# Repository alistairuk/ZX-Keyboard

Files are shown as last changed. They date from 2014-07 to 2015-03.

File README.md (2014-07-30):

ZX-Keyboard
===========

An Arduino based project to convert a broken ZX Spectrum computer in to a USB keyboard.

The full background to this is on by blog at http://www.agm.me.uk/blog/2014/07/zx-keyboard.php
The master source repository is here at https://github.com/alistairuk/ZX-Keyboard
The original build instructions are at http://hackaday.io/project/2076-ZX-Keyboard

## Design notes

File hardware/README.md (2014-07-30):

ZX-Keyboard - Hardware
======================

An Arduino based project to convert a broken ZX Spectrum computer in to a USB keyboard.

This is where we store hardware related documents and diagrams.

The main circuite diagram is produced in fritzing ( http://fritzing.org/download/ ) and exported to PDF.

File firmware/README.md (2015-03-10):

ZX-Keyboard - Hardware
======================

An Arduino based project to convert a broken ZX Spectrum computer in to a USB keyboard.

This is where we store the Arduino sketch for the firmware.

Please note that the VUSB may not compile with the Arduino IDE 1.6 or later. It will compile with 1.0.5.

Please feel free to improve it.

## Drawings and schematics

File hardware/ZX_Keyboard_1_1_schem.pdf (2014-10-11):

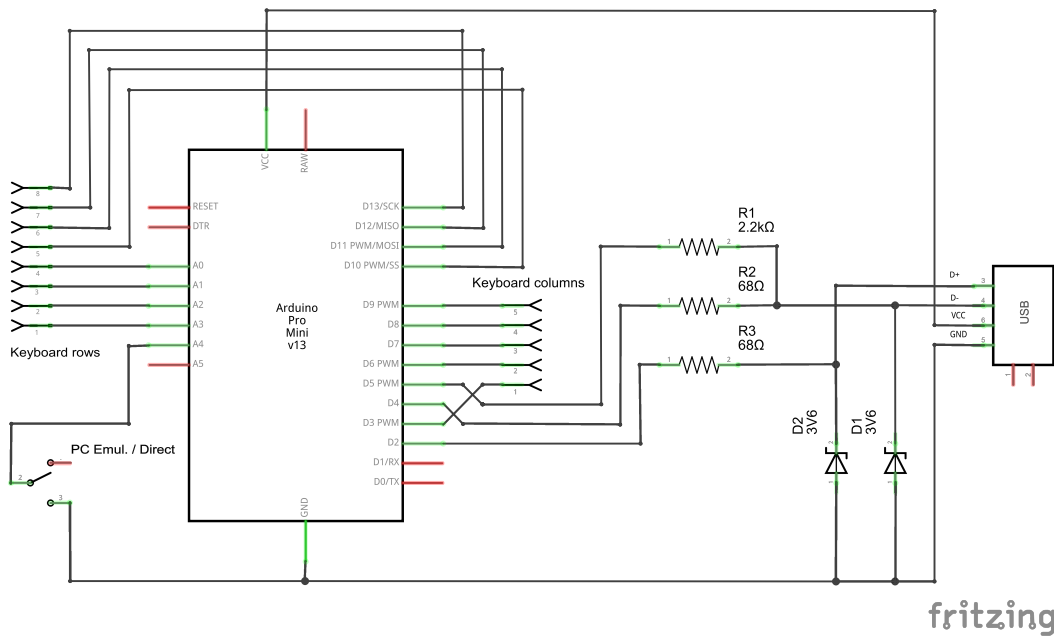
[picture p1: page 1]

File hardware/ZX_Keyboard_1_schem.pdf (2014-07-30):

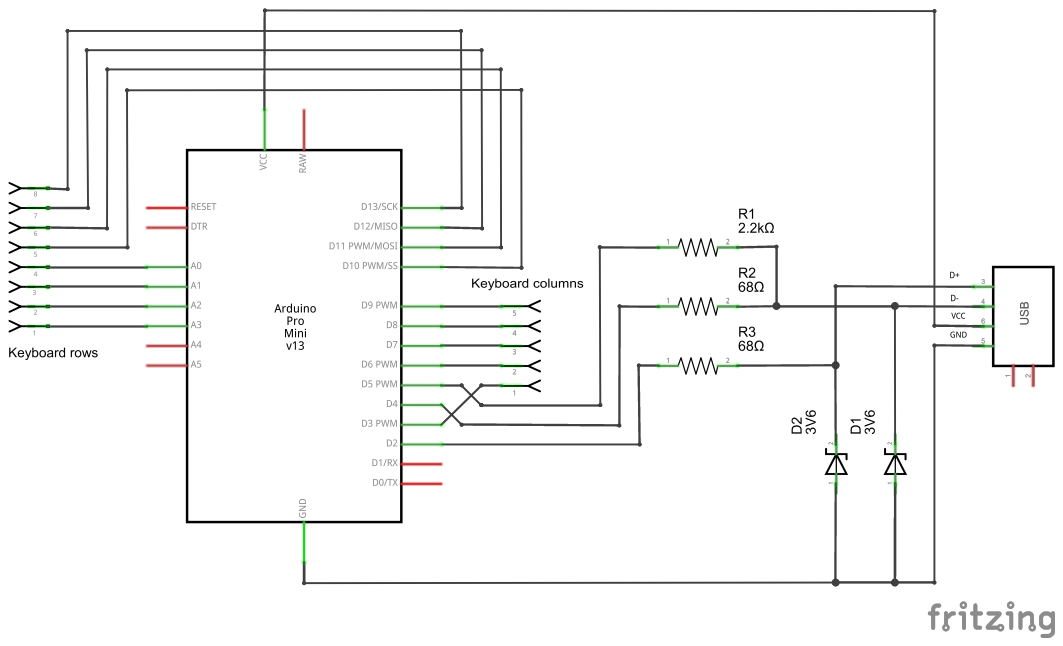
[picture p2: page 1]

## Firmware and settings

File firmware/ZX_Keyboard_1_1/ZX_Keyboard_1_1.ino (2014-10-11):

/*
 * ZX Keyboard
 *
 * Arduino code to use a ZX Spectrum keyboard as a USB keyboard
 *
 * Alistair MacDonald 2014
 *
 */

/*
 * We use the VUSB for Arduino library from http://code.google.com/p/vusb-for-arduino/
 * Download vusb-for-arduino-005 and copy UsbKeyboard from the libraries folder to your libraries folder
 *
 * The Arduino's LED on pin 13 needs to be removed or a pullup resistor to VCC added. This is becuase we use the pin in in INPUT_PULLUP mode.
 *
 * The hardware is as follows....
 *
 * D2 -> 68R Resistor - > USB D+
 * D4 -> 68R Resistor - > USB D-
 * D5 -> 2K2 Resistor - > USB D-
 *
 * USB D+ and D- should be attached to two 3V6 0.5W Zener diodes wiht the anodes connected to ground
 *
 * D3 -> Keyboard Column 1
 * D6 -> Keyboard Column 2
 * D7 -> Keyboard Column 3
 * D8 -> Keyboard Column 4
 * D9 -> Keyboard Column 5
 * PC mapping enable/disable switch -> A4
 * Keyboard Row 1 -> A3
 * Keyboard Row 2 -> A2
 * Keyboard Row 3 -> A1
 * Keyboard Row 4 -> A0
 * Keyboard Row 5 -> D10
 * Keyboard Row 6 -> D11
 * Keyboard Row 7 -> D12
 * Keyboard Row 8 -> D13
 *
 * Full background at http://www.agm.me.uk/blog/2014/07/zx-keyboard.php
 * Master source repository at https://github.com/alistairuk/ZX-Keyboard (please feed back and contribute)
 * Original build instructions at http://hackaday.io/project/2076-ZX-Keyboard
 *
 * Apologies for this not being as readable as I would like. Some parts are a little more complex than  they might at first appear.
 *
 * Changes:
 *
 * 1.0 - Original firmware release
 *
 * 1.1 - Added a switch to A4 to enable / disable PC key mapping
 *
 */
 
#include "UsbKeyboard.h"

// Global varables
byte currentPressed[5]; // Stores the bitmask for currently pressed buttons
byte lastPressed[5];    // Stores the bitmask for the buttons pressed last time
uchar reportBuffer[4];  // Buffer for HID data (1 modifier byte and up to 3 keys)

// Setup everything
void setup() {
  // Set column pins to floating
  pinMode(3, INPUT);
  pinMode(6, INPUT);
  pinMode(7, INPUT);
  pinMode(8, INPUT);
  pinMode(9, INPUT);
  // Set row pins to pullup
  pinMode(10, INPUT_PULLUP);
  pinMode(11, INPUT_PULLUP);
  pinMode(12, INPUT_PULLUP);
  pinMode(13, INPUT_PULLUP);
  pinMode(A0, INPUT_PULLUP);
  pinMode(A1, INPUT_PULLUP);
  pinMode(A2, INPUT_PULLUP);
  pinMode(A3, INPUT_PULLUP);
  pinMode(A4, INPUT_PULLUP);
  // Disable timer0 overflow interrupt
  // This is done to prevent it interupting USB communication
  TIMSK0&=!(1<<TOIE0);
}

// A dleay rputeen with the same functionality as delay() but will work with timer0 disabled
void delay2(unsigned long inDelay) {
  for (int loopIt=0; loopIt<inDelay; loopIt++) {
    delayMicroseconds(1000);
  }
}

// Read the state of one row of keys
byte readRow(int rowPin) {
  // Seet the row pin to low
  pinMode(rowPin, OUTPUT);
  digitalWrite(rowPin, LOW);
  // Read the values from the columns
  // Sorry about it looking complex. It does the same as 8 digitalRead() calls.
  byte result = (~PINB>>2 & B00001111) | (~PINC<<4 & B11110000);
  // Set the row pin back to floating
  pinMode(rowPin, INPUT);
  // All done, return the value  
  return result;
}

// Clear the buffer for HID data
void clearReportBuffer() {
  memset(reportBuffer, 0, sizeof(reportBuffer));
}

// Insert one keycode to the buffer for HID data
void addReportBufferValue(int inKeystroke) {
  memcpy(reportBuffer+2, reportBuffer+1, sizeof(reportBuffer)-2);
  reportBuffer[1] = inKeystroke;
}

// Populate the HID buffer based on the currently pressed buttons in currentPressed[] (PC mapping)
void fillReportBuffer() {
  // Check what keys are being pressed to work out shift state
  int isShiftPressed = currentPressed[0]&0x04;
  int isNumberPressed = ((currentPressed[0]&0x90) || (currentPressed[1]&0x90) || (currentPressed[2]&0x90) || (currentPressed[3]&0x90) || (currentPressed[4]&0x90));
  int isLetterPressed = ((currentPressed[0]&0x6B) || (currentPressed[1]&0x6F) || (currentPressed[2]&0x6F) || (currentPressed[3]&0x6F) || (currentPressed[4]&0x6F)); // Ignore shift here
  // Set the shift modifier is shift is pressed, but only if no numbers (used for navigation) are pressed or a letter (and other non-number keys) is pressed
  // As odd as it is this will work fully under normal circumstances but will also increase compatibility when used with ZX Spectrum emulators
  int isShifted = isShiftPressed && (!isNumberPressed || isLetterPressed);
  reportBuffer[0] = isShifted ? 0x02 : 0x00;
  // Add keycodes for any keys pressed to the HID buffer
  // Row 0
  // Note: We only chage the modifyer when Caps Shift is pressed
  if (currentPressed[0]&0x01) addReportBufferValue(KEY_SPACE);
  if (currentPressed[0]&0x02) addReportBufferValue(KEY_ENTER);
  if (currentPressed[0]&0x08) addReportBufferValue(KEY_P);
  if (!isShiftPressed && (currentPressed[0]&0x10)) addReportBufferValue(KEY_0);
  if (isShiftPressed && (currentPressed[0]&0x10)) addReportBufferValue(0x022A); // Backspace
  if (currentPressed[0]&0x20) addReportBufferValue(KEY_A);
  if (currentPressed[0]&0x40) addReportBufferValue(KEY_Q);
  if (currentPressed[0]&0x80) addReportBufferValue(KEY_1);
  // Row 1
  // Note: This is not called when Symbol Shift is pressed
  if (currentPressed[1]&0x02) addReportBufferValue(KEY_L);
  if (currentPressed[1]&0x08) addReportBufferValue(KEY_O);
  if (currentPressed[1]&0x10) addReportBufferValue(KEY_9);
  if (currentPressed[1]&0x04) addReportBufferValue(KEY_Z);
  if (currentPressed[1]&0x20) addReportBufferValue(KEY_S);
  if (currentPressed[1]&0x40) addReportBufferValue(KEY_W);
  if (!isShiftPressed && (currentPressed[1]&0x80)) addReportBufferValue(KEY_2);
  if (isShiftPressed && (currentPressed[1]&0x80)) addReportBufferValue(0x0039); // Caps Lock
  // Row 2
  if (currentPressed[2]&0x01) addReportBufferValue(KEY_M);
  if (currentPressed[2]&0x02) addReportBufferValue(KEY_K);
  if (currentPressed[2]&0x08) addReportBufferValue(KEY_I);
  if (!isShiftPressed && (currentPressed[2]&0x10)) addReportBufferValue(KEY_8);
  if (isShiftPressed && (currentPressed[2]&0x10)) addReportBufferValue(0x004F); // Right Arrow
  if (currentPressed[2]&0x04) addReportBufferValue(KEY_X);
  if (currentPressed[2]&0x20) addReportBufferValue(KEY_D);
  if (currentPressed[2]&0x40) addReportBufferValue(KEY_E);
  if (currentPressed[2]&0x80) addReportBufferValue(KEY_3);
  // Row 3
  if (currentPressed[3]&0x01) addReportBufferValue(KEY_N);
  if (currentPressed[3]&0x02) addReportBufferValue(KEY_J);
  if (currentPressed[3]&0x08) addReportBufferValue(KEY_U);
  if (!isShiftPressed && (currentPressed[3]&0x10)) addReportBufferValue(KEY_7);
  if (isShiftPressed && (currentPressed[3]&0x10)) addReportBufferValue(0x0052); // Down Arrow
  if (currentPressed[3]&0x04) addReportBufferValue(KEY_C);
  if (currentPressed[3]&0x20) addReportBufferValue(KEY_F);
  if (currentPressed[3]&0x40) addReportBufferValue(KEY_R);
  if (currentPressed[3]&0x80) addReportBufferValue(KEY_4);
  // Row 4
  if (currentPressed[4]&0x01) addReportBufferValue(KEY_B);
  if (currentPressed[4]&0x02) addReportBufferValue(KEY_H);
  if (currentPressed[4]&0x08) addReportBufferValue(KEY_Y);
  if (!isShiftPressed && (currentPressed[4]&0x10)) addReportBufferValue(KEY_6);
  if (isShiftPressed && (currentPressed[4]&0x10)) addReportBufferValue(0x0051); // Down Arrow
  if (currentPressed[4]&0x04) addReportBufferValue(KEY_V);
  if (currentPressed[4]&0x20) addReportBufferValue(KEY_G);
  if (currentPressed[4]&0x40) addReportBufferValue(KEY_T);
  if (!isShiftPressed && (currentPressed[4]&0x80)) addReportBufferValue(KEY_5);
  if (isShiftPressed && (currentPressed[4]&0x80)) addReportBufferValue(0x0050); // Left Arrow
}

// Populate the HID buffer based on the currently pressed buttons in currentPressed[] (direct mapping)
void fillReportBufferDirect() {
  // Check what keys are being pressed to work out shift state
  int isCapsPressed = currentPressed[0]&0x04;
  int isSymbolPressed = currentPressed[1]&0x01;
  // Set the shift modifier is shift is pressed, but only if no numbers (used for navigation) are pressed or a letter (and other non-number keys) is pressed
  // As odd as it is this will work fully under normal circumstances but will also increase compatibility when used with ZX Spectrum emulators
  reportBuffer[0] = (isCapsPressed ? 0x02 : 0x00) + (isSymbolPressed ? 0x01 : 0x00);
  // Add keycodes for any keys pressed to the HID buffer
  // Row 0
  // Note: We only chage the modifyer when Caps Shift is pressed
  if (currentPressed[0]&0x01) addReportBufferValue(KEY_SPACE);
  if (currentPressed[0]&0x02) addReportBufferValue(KEY_ENTER);
  if (currentPressed[0]&0x08) addReportBufferValue(KEY_P);
  if (currentPressed[0]&0x10) addReportBufferValue(KEY_0);
  if (currentPressed[0]&0x20) addReportBufferValue(KEY_A);
  if (currentPressed[0]&0x40) addReportBufferValue(KEY_Q);
  if (currentPressed[0]&0x80) addReportBufferValue(KEY_1);
  // Row 1
  // Note: We only chage the modifyer when Symbol Shift is pressed
  if (currentPressed[1]&0x02) addReportBufferValue(KEY_L);
  if (currentPressed[1]&0x08) addReportBufferValue(KEY_O);
  if (currentPressed[1]&0x10) addReportBufferValue(KEY_9);
  if (currentPressed[1]&0x04) addReportBufferValue(KEY_Z);
  if (currentPressed[1]&0x20) addReportBufferValue(KEY_S);
  if (currentPressed[1]&0x40) addReportBufferValue(KEY_W);
  if (currentPressed[1]&0x80) addReportBufferValue(KEY_2);
  // Row 2
  if (currentPressed[2]&0x01) addReportBufferValue(KEY_M);
  if (currentPressed[2]&0x02) addReportBufferValue(KEY_K);
  if (currentPressed[2]&0x08) addReportBufferValue(KEY_I);
  if (currentPressed[2]&0x10) addReportBufferValue(KEY_8);
  if (currentPressed[2]&0x04) addReportBufferValue(KEY_X);
  if (currentPressed[2]&0x20) addReportBufferValue(KEY_D);
  if (currentPressed[2]&0x40) addReportBufferValue(KEY_E);
  if (currentPressed[2]&0x80) addReportBufferValue(KEY_3);
  // Row 3
  if (currentPressed[3]&0x01) addReportBufferValue(KEY_N);
  if (currentPressed[3]&0x02) addReportBufferValue(KEY_J);
  if (currentPressed[3]&0x08) addReportBufferValue(KEY_U);
  if (currentPressed[3]&0x10) addReportBufferValue(KEY_7);
  if (currentPressed[3]&0x04) addReportBufferValue(KEY_C);
  if (currentPressed[3]&0x20) addReportBufferValue(KEY_F);
  if (currentPressed[3]&0x40) addReportBufferValue(KEY_R);
  if (currentPressed[3]&0x80) addReportBufferValue(KEY_4);
  // Row 4
  if (currentPressed[4]&0x01) addReportBufferValue(KEY_B);
  if (currentPressed[4]&0x02) addReportBufferValue(KEY_H);
  if (currentPressed[4]&0x08) addReportBufferValue(KEY_Y);
  if (currentPressed[4]&0x10) addReportBufferValue(KEY_6);
  if (currentPressed[4]&0x04) addReportBufferValue(KEY_V);
  if (currentPressed[4]&0x20) addReportBufferValue(KEY_G);
  if (currentPressed[4]&0x40) addReportBufferValue(KEY_T);
  if (currentPressed[4]&0x80) addReportBufferValue(KEY_5);
}

// Lookup the key ID for a key when Symbol Shift is pressed
// The modifyer (the shift state) is returned in the upper byte
// Some keys remain unshifted to increase compatibility when used with ZX Spectrum emulators
word keyToSymbol(byte inCol, byte inRow) {
  word ourKeyCode = inCol<<8 | inRow;
  switch (ourKeyCode) {
    // Row 0
    case 0x0001: return KEY_SPACE; // Space
    case 0x0002: return KEY_ENTER; // Enter
    case 0x0008: return 0x021F; // "
    case 0x0010: return 0x022D; // _
    case 0x0004: return 0x00E1; // Caps Shift
    case 0x0020: return 0x0232; // ~
    case 0x0040: return KEY_Q;  // Q
    case 0x0080: return 0x021E; // !
    // Row 1
    case 0x0101: return 0x00E4; // Symbol Shift
    case 0x0102: return 0x002E; // =
    case 0x0108: return 0x0033; // ;
    case 0x0110: return 0x0227; // )
    case 0x0104: return 0x0233; // :
    case 0x0120: return 0x0264; // |
    case 0x0140: return KEY_W;  // W
    case 0x0180: return 0x0234; // @
    // Row 2
    case 0x0201: return 0x0037; // .
    case 0x0202: return 0x022E; // +
    case 0x0208: return KEY_I;  // I
    case 0x0210: return 0x0226; // (
    case 0x0204: return 0x0220; // £
    case 0x0220: return 0x0064; // Backslash
    case 0x0240: return KEY_E;  // E
    case 0x0280: return 0x0032; // #
    // Row 3
    case 0x0301: return 0x0036; // ,
    case 0x0302: return 0x002D; // -
    case 0x0308: return 0x0030; // ]
    case 0x0310: return 0x0034; // '
    case 0x0304: return 0x0238; // ?
    case 0x0320: return 0x022F; // {
    case 0x0340: return 0x0236; // <
    case 0x0380: return 0x0221; // $
    // Row 4
    case 0x0401: return 0x0225; // *
    case 0x0402: return 0x0223; // ^
    case 0x0408: return 0x002F; // [
    case 0x0410: return 0x0224; // &
    case 0x0404: return 0x0038; // /
    case 0x0420: return 0x0230; // }
    case 0x0440: return 0x0237; // >
    case 0x0480: return 0x0222; // %
    // Default
    default: return 0;
  }
}

// Populate and send the HID buffer based on currentPressed[]
void SendNormalStrokes(int inDirect = false) {
  // Wait until any past keystrokes are sent
  while (!usbInterruptIsReady());
  // Clear the current values before we add the new ones
  clearReportBuffer();
  // Fill the buffer for the keys pressed
  if (inDirect) {
    // Direct mapping
    fillReportBufferDirect();
  }
  else {
    // PC mapping
    fillReportBuffer();
  }
  // Send the buffer across the USB
  usbSetInterrupt(reportBuffer, sizeof(reportBuffer));
}

// Build and send the HID buffer for a symbol
// onCol specified the column and inRow is a bitmask of the key that was pressed
word sendSymbolKeystroke(byte inCol, byte inRow) {
  // Wait until any past keystrokes are sent
  while (!usbInterruptIsReady());
  // Clear the current values before we add the new ones
  clearReportBuffer();
  // Lookup the keycode and put it in the HID buffer
  word usbKeycode = keyToSymbol(inCol, inRow);
  reportBuffer[0] = usbKeycode>>8 & 0xFF; // Modifyer stored in the upper byte
  reportBuffer[1] = usbKeycode & 0xFF;    // Keycode stored in the lower byte
  // Send the buffer across the USB
  usbSetInterrupt(reportBuffer, sizeof(reportBuffer));
  // Wait until any past keystrokes are sent
  while (!usbInterruptIsReady());
  // Clear the current values to simulate the key being released
  clearReportBuffer();
  // Send the empty buffer across the USB
  usbSetInterrupt(reportBuffer, sizeof(reportBuffer));
}

// Constants used for keyMode
#define KEYMODE_NORMAL 0
#define KEYMODE_SYMBOL 1

int keyMode = KEYMODE_NORMAL; // Has the Symbol Shift been pressed?
byte changedRow;              // Used to track what has changed in a row

void loop() {

  // Poll the USB so the computer knows we are alive
  usbPoll();

  // Read in the keyboard status
  currentPressed[0] = readRow(3);
  currentPressed[1] = readRow(6);
  currentPressed[2] = readRow(7);
  currentPressed[3] = readRow(8);
  currentPressed[4] = readRow(9);

  // Check if a key has changed
  if ((lastPressed[0]!=currentPressed[0]) ||
      (lastPressed[1]!=currentPressed[1]) ||
      (lastPressed[2]!=currentPressed[2]) ||
      (lastPressed[3]!=currentPressed[3]) ||
      (lastPressed[4]!=currentPressed[4])) {

    
    // Check if the switch has PC key mapping disabled
    if (!digitalRead(A4)) {
      SendNormalStrokes(true);
    }
    
    // Otherwise the switch has PC key mapping enabled
    else {
        
      // Send symbol if Symbol Shift pressed
      if (currentPressed[1]&0x01) {
        // We are now in symbol mode until all the buttons are released
        keyMode = KEYMODE_SYMBOL;
        // Loop though each of the rows read
        for (int loopCol=0; loopCol<sizeof(currentPressed); loopCol++) {
          // Check if any of the buttons have just been pressed and send the keystroke if they have.
          changedRow = currentPressed[loopCol] & ~lastPressed[loopCol];
          if (changedRow) {
            sendSymbolKeystroke(loopCol, changedRow);
          }
        }
      }
    
      // Reset key mode if no key pressed (ignoring shift)
      // We wait for no keys to prevent sending a lot of keys when Symbol Shift is released
      if (((currentPressed[0]&0xFB) | currentPressed[1] | currentPressed[2] | currentPressed[3] | currentPressed[4])==0x00) {
        keyMode = KEYMODE_NORMAL;
      }
    
      // Send keystrokes if in normal operation1
      if (keyMode==KEYMODE_NORMAL) {
        SendNormalStrokes(false);
      }

    }

    // Remember that last state of the keyboard
    memcpy(lastPressed, currentPressed, sizeof(lastPressed));
    
    // Poor man's debounce
    // Yes it is a very long time but these old rubber keyboard have a lot of bounce 
    // We can't use delay() as we disabled timer0 se we use our delay2() replacement
    delay2(80);

  }
  else {
    // No key was pressed so save some power by sleeping a little
    // We can't use delay() as we disabled timer0 se we use our delay2() replacement
    delay2(20);
  }
}

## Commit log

2014-07-30 Initial check in of version 1
    [ZX_Keyboard_1.fzz]
2014-10-11 Added support for "Direct" non-PC mapped mode.
    [ZX_Keyboard_1_1.fzz]
2015-03-10 Added not able Arduino IDE version compatibility
